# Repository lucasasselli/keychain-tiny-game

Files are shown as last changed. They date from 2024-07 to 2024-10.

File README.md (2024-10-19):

# Keychain Tiny Game

<p align="center">
  
</p>

# Features
- Beautiful state of the art 1D graphics
- One button gameplay
- Can hold keys
- No microtransactions

# The idea
I recently bought a novelty keychain: it's a handmade leather pouch designed to protect my phone screen from scratches while adding a touch of style. Unfortunately, it’s more of a hindrance than a help, making it difficult to use my keys and turning me into a bumbling character from a horror movie that can't open the door to safety. That truth is that keys are naturally scratchy, and they seem to resent being kept away from their preferred surfaces. 

This keychain isn’t just a time-wasting game for dentist appointments, it’s also a collection of 24 tiny, sharp SMD components waiting to sand down my phone screen the first time I accidentally put it in the wrong pocket.

# Gameplay
Press the button when the spinning light reaches the target. Do it again slightly faster. Repeat until it's your turn at the dentist, doctor, barber, etc...

# Hardware
The board utilizes an ATtiny25 microcontroller running at 1MHz to drive 16 LEDs via [Charlieplexing](https://en.wikipedia.org/wiki/Charlieplexing). A single button on the back of the board allows for game control. The device is powered by a single CR2032 coin cell battery.

<p align="center">
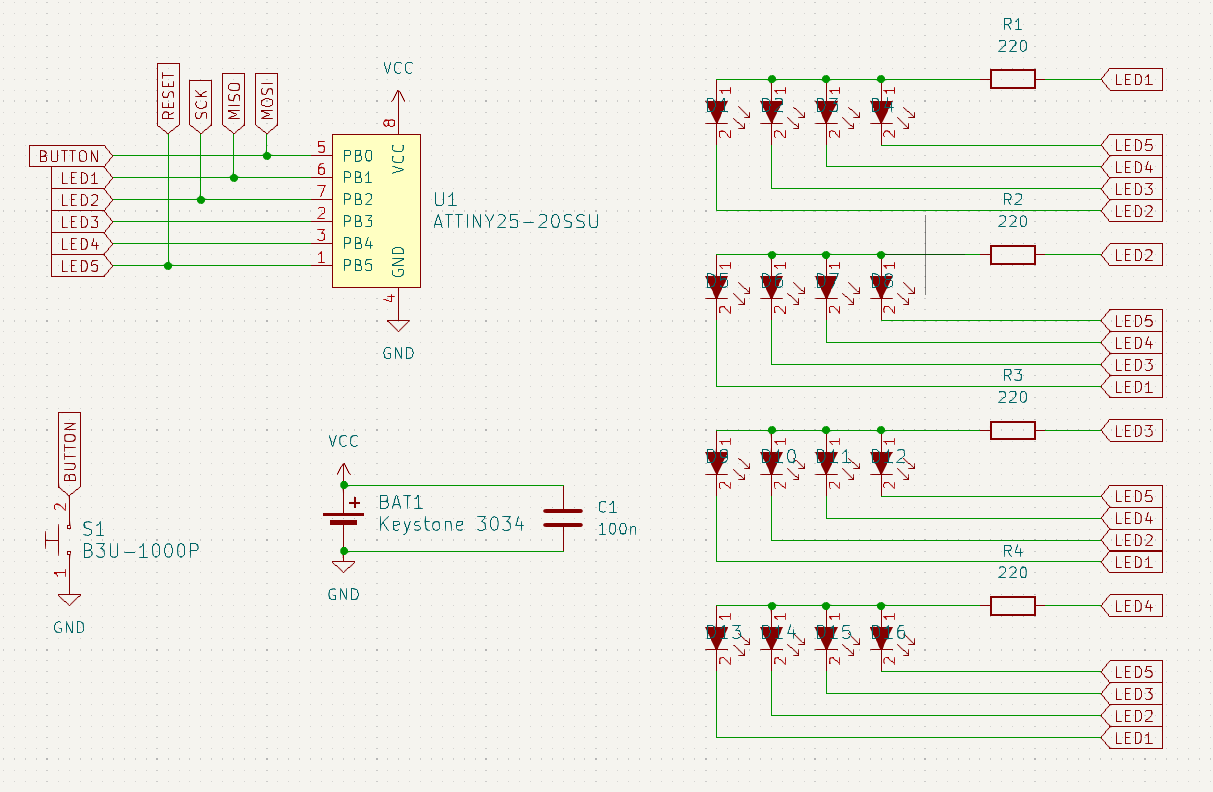
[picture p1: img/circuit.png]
  
</p>

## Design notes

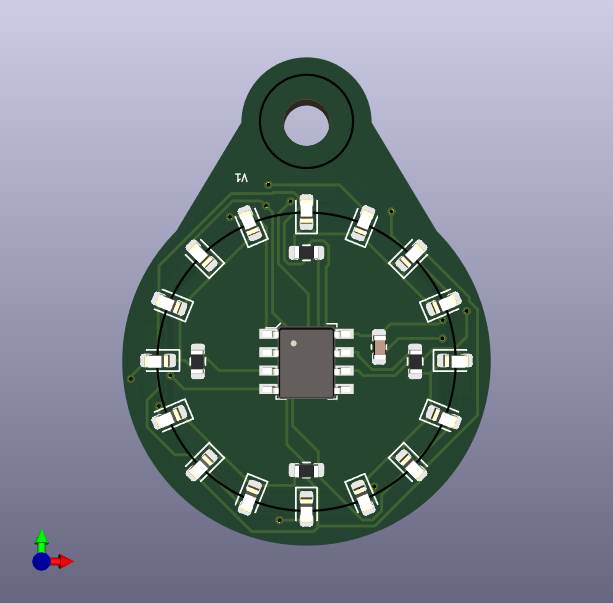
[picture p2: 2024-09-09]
img/render1.png

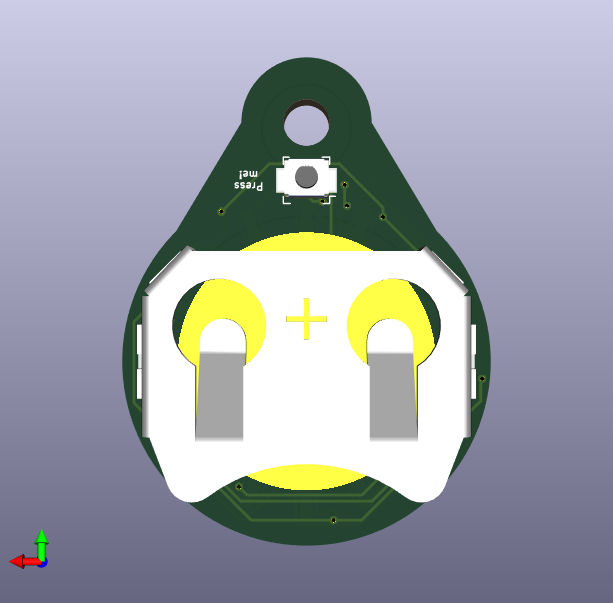
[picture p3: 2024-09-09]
img/render2.png

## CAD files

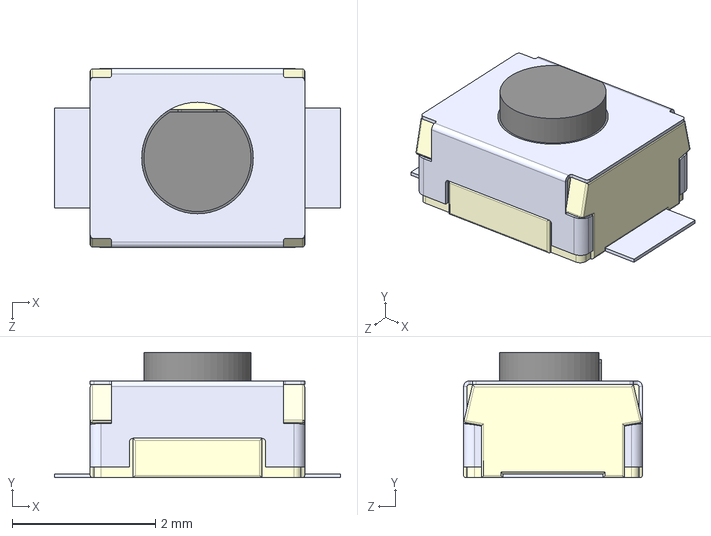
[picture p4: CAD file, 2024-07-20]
hardware/3d/B3U-1000P.step
4.00 x 1.75 x 2.50 mm

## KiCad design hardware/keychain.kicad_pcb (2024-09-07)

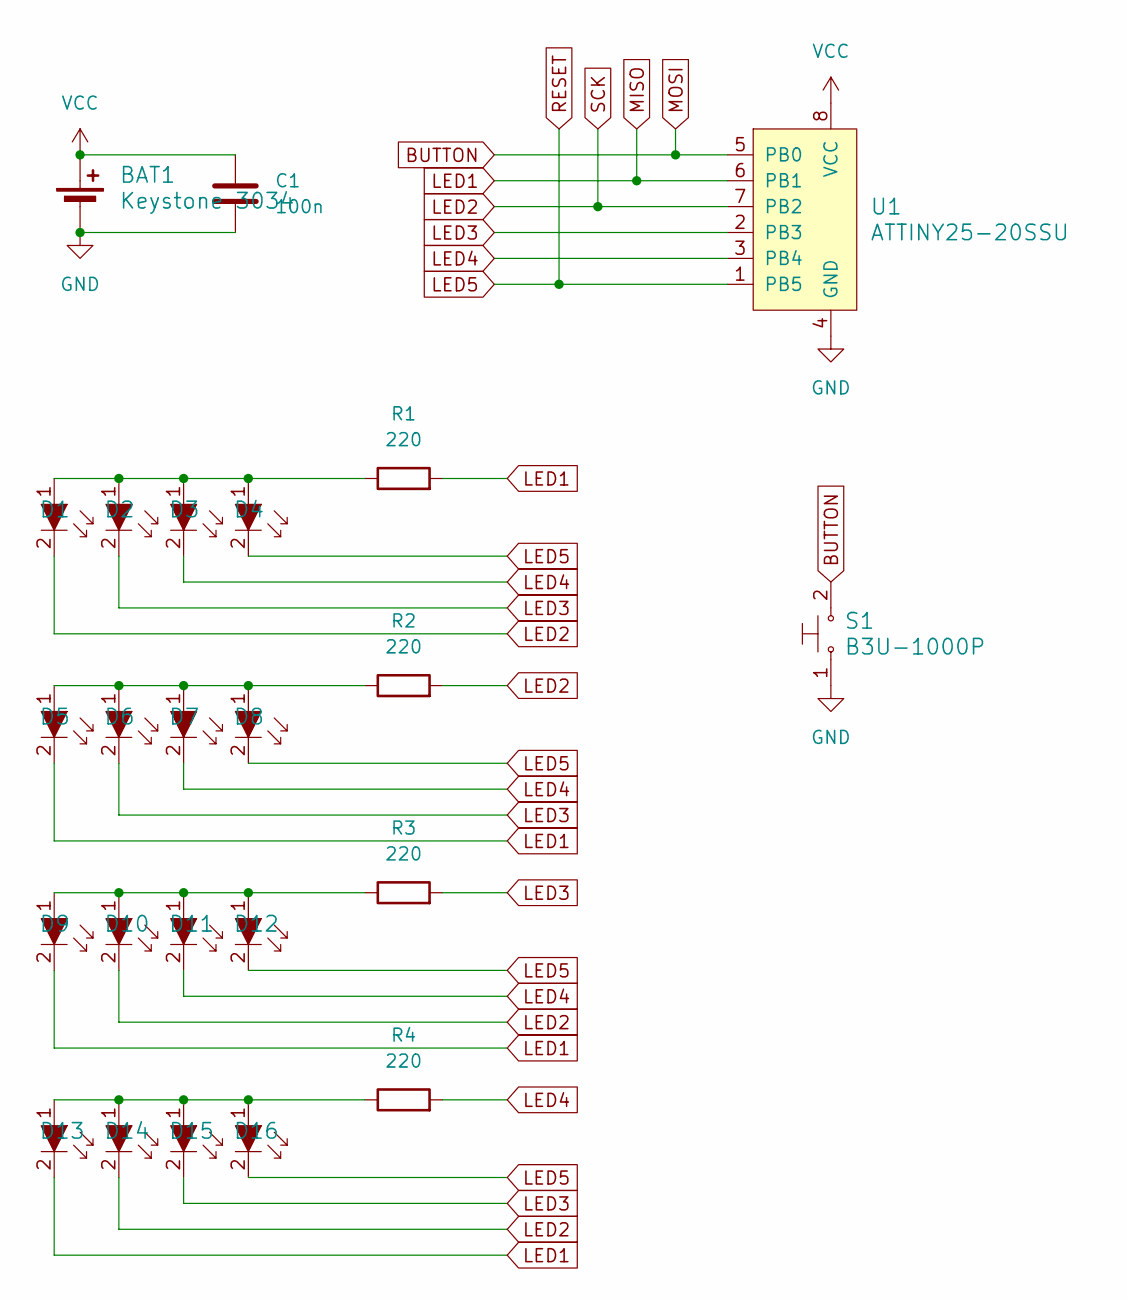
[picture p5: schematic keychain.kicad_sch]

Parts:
BAT1: Keystone 3034; BatteryHolder_Keystone_3034_1x20mm; MPN BS-7; Digi-Key_PN BS-7-ND
C1: 100n; C_0603_1608Metric
D1, D2, D3, D4, D5, D6, D7, D8, D9, D10, D11, D12, D13, D14, D15, D16: LH_R974-LP-1; 0805; MPN LH R974-LP-1; Digi-Key_PN 475-1415-1-ND
R1, R2, R3, R4: 220; R_0603_1608Metric
S1: B3U-1000P; Switch_Tactile_SMD_B3U-1000P; MPN B3U-1000P; Digi-Key_PN SW1020CT-ND
U1: ATTINY25-20SSU; SOIC-8_W5.3mm; MPN ATTINY85-20SU; Digi-Key_PN ATTINY85-20SU-ND

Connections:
BUTTON: S1.2, U1.5 (PB0)
GND: BAT1.2 (-), C1.1, S1.1, U1.4 (GND)
LED1: D5.2, D9.2, D13.2, R1.2, U1.6 (PB1)
LED2: D1.2, D10.2, D14.2, R2.2, U1.7 (PB2)
LED3: D2.2, D6.2, D15.2, R3.2, U1.2 (PB3)
LED4: D3.2, D7.2, D11.2, R4.2, U1.3 (PB4)
LED5: D4.2, D8.2, D12.2, D16.2, U1.1 (PB5)
unnamed: D1.1, D2.1, D3.1, D4.1, R1.1
unnamed: D5.1, D6.1, D7.1, D8.1, R2.1
unnamed: D9.1, D10.1, D11.1, D12.1, R3.1
unnamed: D13.1, D14.1, D15.1, D16.1, R4.1
VCC: BAT1.1 (+), C1.2, U1.8 (VCC)

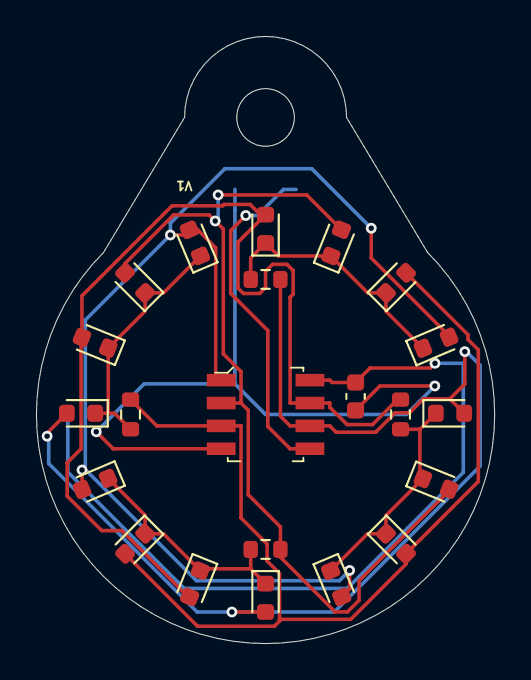
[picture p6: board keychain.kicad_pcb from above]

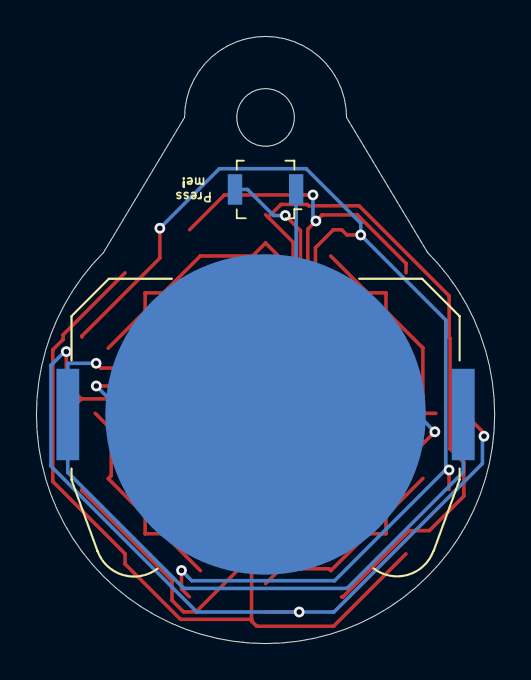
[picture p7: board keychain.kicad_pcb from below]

Board: 2 copper layers, 25.5 x 33.7 mm, 24 parts (2 on the bottom side), 12 nets.

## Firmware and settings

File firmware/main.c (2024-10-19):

#include <avr/interrupt.h>
#include <avr/io.h>
#include <avr/sleep.h>
#include <stdlib.h>

#define BIT(pos) (1 << (pos))
#define GET_BIT(x, pos) ((x >> pos) & 1)
#define SET_BIT(x, pos) ((x) |= (BIT(pos)))
#define CLEAR_BIT(x, pos) ((x) &= ~(BIT(pos)))

#define LED_CNT 16

#define BTN_DEBOUNCE_NUM 10
#define BTN_PIN PB0

#define CURSOR_TIME_BASE 800
#define CURSOR_TIME_STAGE_DELTA 16
#define INIT_SPIN_TIME 100
#define INIT_SPIN_NUM 3
#define FAIL_TIME 8000
#define GAME_TIMEOUT 40000
#define GAME_MAX_STAGES 45
#define WIN_TIME 8000

const uint8_t cplex_pins[LED_CNT][2] = {
    // Group 0
    {PB1, PB2},
    {PB1, PB3},
    {PB1, PB4},
    {PB1, PB5},

    // Group 1
    {PB2, PB1},
    {PB2, PB3},
    {PB2, PB4},
    {PB2, PB5},

    // Group 2
    {PB3, PB1},
    {PB3, PB2},
    {PB3, PB4},
    {PB3, PB5},

    // Group 3
    {PB4, PB1},
    {PB4, PB2},
    {PB4, PB3},
    {PB4, PB5},
};

typedef enum {
    GAME_INIT,
    GAME_ACTIVE,
    GAME_FAIL,
    GAME_WIN
} game_state_t;

// Game
game_state_t game_state;  // Current game state
uint8_t game_init_cnt;    // Number of loops furing init animation
uint8_t game_stage;       // Stage
uint8_t game_target;      // Target light position
uint8_t game_cursor;      // Cursor light position
uint8_t game_dir;         // Cursor direction

uint16_t idle_time = 0;
uint16_t timer_ovf_cnt = 0;

// Button
uint8_t btn_pressed_cnt;  // De-bounce counter
uint8_t btn_state;        // Button filtered state
uint8_t btn_old_state;    // Button old state (for edge detection)

void game_target_rand() {
    game_target = rand() % LED_CNT;  // Pick a new target
#ifdef SKIP_RST_PIN
    if ((game_target % 4) == 3) game_target_rand();
#endif
}

void game_init() {
    // Configure timer
    TCCR0A = 0x00;  // Normal mode
    TCCR0B = 0x00;
    TCCR0B |= (1 << CS00);  // No prescaling
    TCNT0 = 0;

    // Configure button pin as input with pull-up resistor
    DDRB &= ~(1 << BTN_PIN);
    SET_BIT(PORTB, BTN_PIN);

    // Setup game
    game_state = GAME_INIT;
    game_init_cnt = 0;
    game_cursor = 0;
    game_dir = 0;
    idle_time = 0;
    timer_ovf_cnt = 0;

    game_target_rand();  // Pick a random target
}

void led_off() {
    PORTB &= (1 << BTN_PIN);
    DDRB &= (1 << BTN_PIN);
}

void led_set_index(uint8_t i) {
    uint8_t val = PORTB & (1 << BTN_PIN);
    uint8_t dir = DDRB & (1 << BTN_PIN);

    SET_BIT(val, cplex_pins[i][0]);
    SET_BIT(dir, cplex_pins[i][0]);
    SET_BIT(dir, cplex_pins[i][1]);

    PORTB = val;
    DDRB = dir;
}

void sleep() {
    // Configure IO
    GIMSK |= _BV(PCIE);    // Enable Pin Change Interrupts
    PCMSK |= _BV(PCINT0);  // Use PB0 as interrupt pin

    DDRB = 0;  // All pin on High-Z

    set_sleep_mode(SLEEP_MODE_PWR_DOWN);

    sleep_enable();  // Sets the Sleep Enable bit in the MCUCR Register (SE BIT)
    sei();           // Enable interrupts
    sleep_cpu();     // sleep

    cli();            // Disable interrupts
    sleep_disable();  // Clear SE bit
}

void cursor_next() {
    if (game_cursor == LED_CNT) {
        game_cursor = 0;
    } else {
        game_cursor++;
    }

#ifdef SKIP_RST_PIN
    if ((game_cursor % 4) == 3) cursor_next();
#endif
}

void cursor_prev() {
    if (game_cursor == 0) {
        game_cursor = LED_CNT - 1;
    } else {
        game_cursor--;
    }
#ifdef SKIP_RST_PIN
    if ((game_cursor % 4) == 3) cursor_prev();
#endif
}

void game_do_init() {
    if (timer_ovf_cnt > INIT_SPIN_TIME) {
        cursor_next();

        if (game_cursor == game_target) {
            game_init_cnt++;
            if (game_init_cnt > INIT_SPIN_NUM) {
                // Init animation complete! Start the game...
                game_state = GAME_ACTIVE;
                game_stage = 0;  // Start from stage 0
            }
        }

        // Reset IRQ counter
        timer_ovf_cnt = 0;
    }

    // Program the LED
    led_set_index(game_cursor);
}

void game_do_active() {
    idle_time++;

    if (timer_ovf_cnt > (CURSOR_TIME_BASE - ((uint16_t)game_stage) * CURSOR_TIME_STAGE_DELTA)) {
        // Move lights clockwise
        if (game_dir) {
            cursor_next();
        } else {
            cursor_prev();
        }

        // Reset IRQ counter
        timer_ovf_cnt = 0;
    }

    // De-bounce button
    if (!GET_BIT(PINB, BTN_PIN)) {
        if (btn_pressed_cnt < BTN_DEBOUNCE_NUM) {
            btn_pressed_cnt++;
        } else {
            btn_state = 1;
        }
    } else {
        if (btn_pressed_cnt > 0) {
            btn_pressed_cnt--;
        } else {
            btn_state = 0;
        }
    }

    if (btn_state == 1 && btn_old_state == 0) {
        // Positive edge
        if (game_cursor == game_target) {
            // Target hit! Move to next stage...
            game_dir ^= 1;       // Change direction
            game_target_rand();  // Pick a random target

            game_stage++;  // Increase the stage
            if (game_stage > GAME_MAX_STAGES) {
                // Game over! Show the win animation...
                game_state = GAME_WIN;
            }
        } else {
            // Target missed! Set state to fail...
            game_state = GAME_FAIL;
        }
        idle_time = 0;
    }

    btn_old_state = btn_state;

    // Tooggle between target and cursor, but keep cursor active more!
    if ((timer_ovf_cnt & 7) == 1) {
        led_set_index(game_target);
    } else {
        led_set_index(game_cursor);
    }

    // Check for idle time and put device to sleep if necessary
    if (idle_time > GAME_TIMEOUT) {
        sleep();
        game_init();
    }
}

void game_do_fail() {
    if (timer_ovf_cnt > FAIL_TIME) {
        // Win animation complete! Start again
        game_init();  // Reset game
    }

    // Blink last cursor LED
    if (GET_BIT(timer_ovf_cnt, 7)) {
        led_set_index(game_cursor);
    } else {
        led_off();
    }
}

void game_do_win() {
    if (timer_ovf_cnt > WIN_TIME) {
        // Win animation complete! Start again
        game_init();  // Reset game
    }

    // Blink all LEDs
    if (GET_BIT(timer_ovf_cnt, 7)) {
        cursor_next();
        led_set_index(game_cursor);
    } else {
        led_off();
    }
}

int main() {
    game_init();

    while (1) {
        // Time game execution with timer overflow
        if (GET_BIT(TIFR, TOV0)) {
            SET_BIT(TIFR, TOV0);  // Clear timer overflow (W1TC)

            // Game logic
            switch (game_state) {
                case GAME_INIT:
                    game_do_init();
                    break;

                case GAME_ACTIVE:
                    game_do_active();
                    break;

                case GAME_FAIL:
                    game_do_fail();
                    break;

                case GAME_WIN:
                    game_do_win();
                    break;
            }

            timer_ovf_cnt++;
        }
    }
}

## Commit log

2024-07-20 Moved the button to the back.
    [microgame.kicad_pcb]
2024-07-27 Updated design to have a sane pin mapping. Added initial simulator program and firmware.
    [microgame.kicad_pcb, microgame.kicad_sch]
2024-09-07 Updated BOM
    [microgame.kicad_pcb, microgame.kicad_sch]
2024-09-09 Renamed hardware project. Code cleanup. Added images.
    [B3U-1000P.step, keychain.kicad_pcb, keychain.kicad_sch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]
